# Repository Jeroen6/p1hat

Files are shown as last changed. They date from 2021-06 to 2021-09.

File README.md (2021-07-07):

# p1hat
Rasbperry Pi P1 Monitor (ztatz.nl) IO HAT

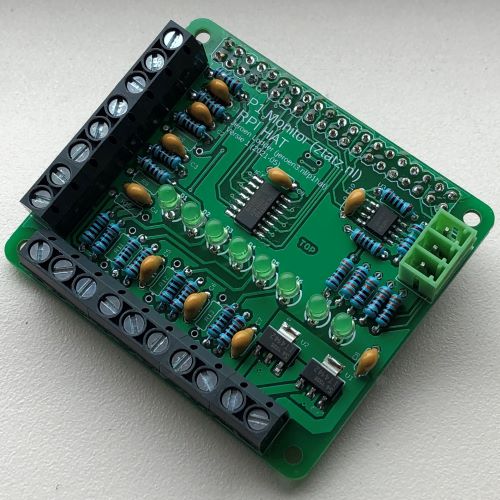
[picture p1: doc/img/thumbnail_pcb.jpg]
pcb


## Behuizing
Er is ook een behuizing!

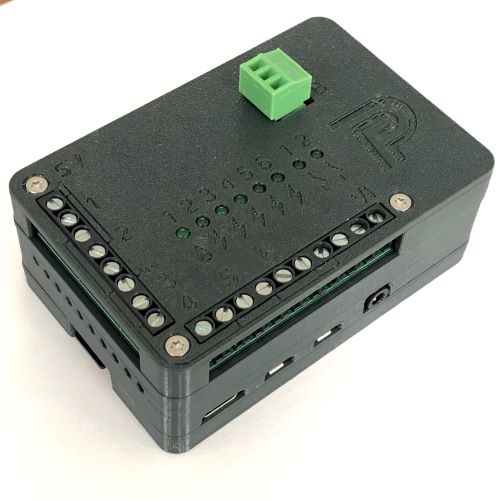
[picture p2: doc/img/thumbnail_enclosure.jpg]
render


## Aansluitingen

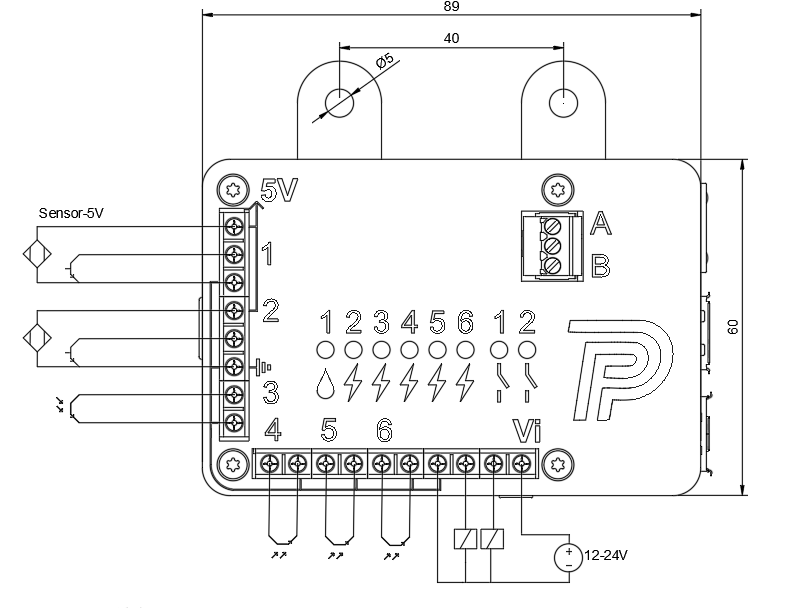
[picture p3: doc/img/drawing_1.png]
aansluitingen


## Inputs

Er zijn 6 gebufferde ingangen geschikt voor open-collector apparaten.
Zoals S0 pulsen van energiemeters of NPN type inductieve sensoren voor watermeters.

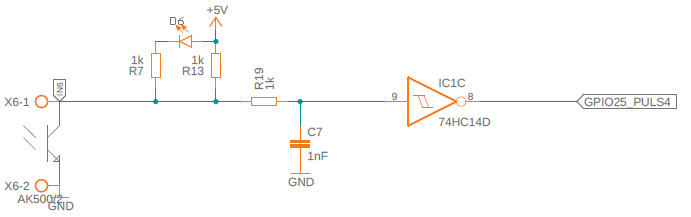
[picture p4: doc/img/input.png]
inputs


Het buffer is een 74LVC07A met schmitt trigger ingangen en open drain uitgangen. 
Hiervoor is het dus nodig om de pull-ups in de BCM te activeren. 
Een ander buffer kan ook, velen passen op deze SOIC footprint.

Het filternetwerk 1k/1nF dempt eventuele ingekoppelde storingen en de sterke pull-up van 1 kOhm voorkomt spontane detecties. *(van nabij schakelende relais, motoren of andere storingen)*  

> Als er schakelaars worden aangesloten dient dit netwerk wellicht te worden vertraagd, probeer 100k en 10nf. Of [debounce](https://en.wikipedia.org/wiki/Switch#Contact_bounce) in software.

## Outputs

Twee smart high side fets kunnen bijna elke 12/45V last schakelen.
 - Ze zijn geschikt voor high-side switching. 
 - Ze zijn geschikt voor inductieve lasten zonder vrijloop diode. (relais)
 - Ze zijn thermisch kortsluitbeveiligd.
 
Vrijwel niet kapot te krijgen.

## RS-485

Op de print zit een RS-485 tranceiver. Om bijvoorbeeld te praten met RS-485 energiemeters.
De middelste pin van de RS-485 header is GND, dit is meestal niet nodig.

> Hoe dit op de raspberry werkt moet ik nog uitzoeken.  

## GPIO Header

| Board | GPIO | Mode |
|---|---|---|
| IN1 | 17 | Pull-up |
| IN2 | 27 | Pull-up |
| IN3 | 22 | Pull-up |
| IN4 | 23 | Pull-up |
| IN5 | 24 | Pull-up |
| IN6 | 25 | Pull-up |
| OUT1 | 26 | Push-Pull  |
| OUT2 | 16 | Push-Pull  |
| RS485 TX | 14 | Alt0 |
| RS485 RX | 15 | Alt0 |
| RS485 TXENABLE | 18 | Push-Pull  |

## BOM

Lijst met onderdelen:

- PCB, zie .txt file in de map PCB voor onderdelen.
    - De onderdelen zijn te krijgen via Conrad, Reichelt of zelfs AliExpress of sinuss.nl (dat is farnell/avnet voor particulieren).
- Raspberry Pi 4 met SD kaart en P1 Monitor
- Behuizing 3D-geprint van PETG.
- Schroeven
    - 4x M2.5x16 Verzonken Torx (TX8) WS 9475TX
    - 4x M2.5x12 Verzonken Torx (TX8) WS 9475TX
        - Zie [rvspaleis.nl](https://www.rvspaleis.nl/bouten/torx/ws-9475/ws-9475-[-]-a2-[-]-m2,5)

> De 1 kOhm pull-ups parallel aan de LED heb ik op mijn print niet geplaatst. Mogelijk zijn deze bij andere typen, of geen, LED's wel nodig.

## Software

De gebruikte software is (gratis) Autodesk Fusion 360 voor niet-commercieel gebruik. 
De `*.f3z` bestanden zijn archieven hiervan.

## Suggesties of problemen?
Zet deze in de [Issues](https://github.com/Jeroen6/p1hat/issues) en vragen in [Discussions](https://github.com/Jeroen6/p1hat/discussions).

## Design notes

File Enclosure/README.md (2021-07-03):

## Wat is dit?

Ik heb twee modellen gemaakt.

1. Origineel gebaseerd op de RPI 4.
2. Kopie met wijzigingen voor RPI 3 op het middelste deel.  
En wijzigingen op de bovenkant zonder enige markings of gaatjes.

In de rpi3 versie step file zit de closed top.

## 3D Printen

Instructies voor printen van de `.stl`:

1. Print een bodem.
2. Print een middendeel voor jouw RPI type.
3. Print een top (zonder de hat kun je de _closed_ variant nemen)

Dit kan tegelijk.

> Let op bij het middendeel, print deze met de RPI zijde onder, die is vlak. Zet ook de supports aan voor de bridges rond de HDMI/USB plugs. In prusaslicer is "support on build plate only" voldoende.

## Fusion360

De twee `*.f3z` bestanden zijn de Fusion360 archieven, om verder te bewerken.

## Assemblage

Het is een sandwich en er is weinig keuzevrijheid.
De lange m2.5x16 schroef gaat boven aan de hat zijde.    
De korte m2.5x12 schroef gaat onder aan de pi zijde.  

De gaten zijn iets te klein, het fijne draad tapt erin. Dit is geen stevige montage.
Je draait dit snel dol, dus als de schroef gelijk is aan het oppervlak zit je goed.  
Het hoeft niet super vast.

Eventueel kun je het model bewerken of uitboren en er threaded-inserts in persen of smelten.

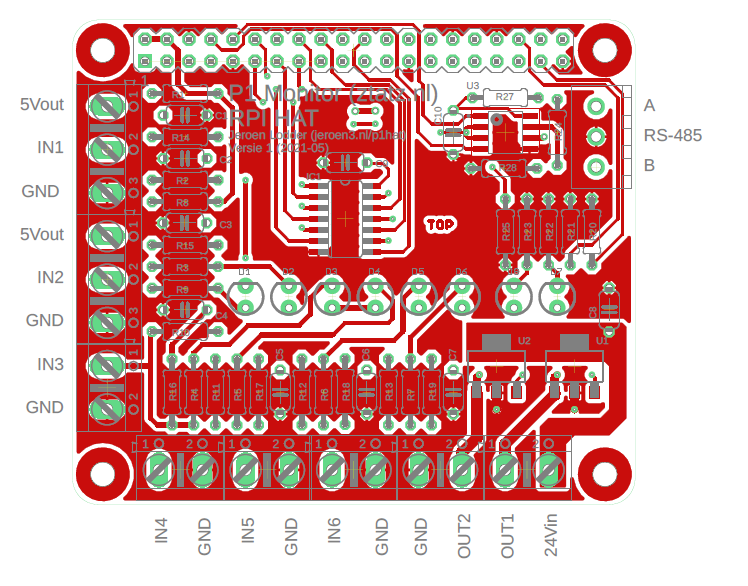
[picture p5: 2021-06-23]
doc/img/pcb-text.png

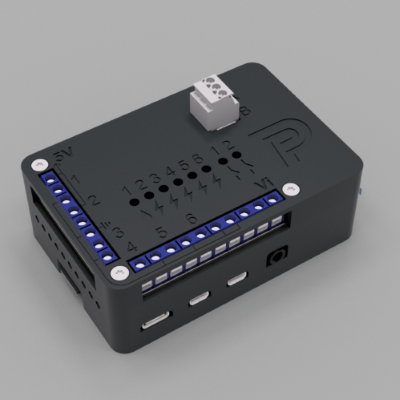
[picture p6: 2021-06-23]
doc/img/renderv20.png

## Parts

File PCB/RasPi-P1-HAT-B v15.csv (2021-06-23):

Part | Value | Device | Package | Description | DIELECTRIC | MF | MPN | OC_FARNELL | OC_NEWARK | POPULARITY | PROD_ID | SPICEPREFIX | TOLERANCE
C1 | 100nF | C-EU050-024X044 | C050-024X044 | CAPACITOR, European symbol | X7R |  |  |  |  | 33 |  | C
C2 | 1nF | C-EU050-024X044 | C050-024X044 | CAPACITOR, European symbol | X7R |  |  |  |  | 33 |  | C
C3 | 1nF | C-EU050-024X044 | C050-024X044 | CAPACITOR, European symbol | X7R |  |  |  |  | 33 |  | C
C4 | 1nF | C-EU050-024X044 | C050-024X044 | CAPACITOR, European symbol | X7R |  |  |  |  | 33 |  | C
C5 | 1nF | C-EU050-024X044 | C050-024X044 | CAPACITOR, European symbol | X7R |  |  |  |  | 33 |  | C
C6 | 1nF | C-EU050-024X044 | C050-024X044 | CAPACITOR, European symbol | X7R |  |  |  |  | 33 |  | C
C7 | 1nF | C-EU050-024X044 | C050-024X044 | CAPACITOR, European symbol | X7R |  |  |  |  | 33 |  | C
C8 | 100nF | C-EU050-024X044 | C050-024X044 | CAPACITOR, European symbol | X7R |  |  |  |  | 33 |  | C
C9 | 1nF | C-EU050-024X044 | C050-024X044 | CAPACITOR, European symbol | X7R |  |  |  |  | 33 |  | C
D1 |  | LED3MM | LED_3MM | LED (Generic) |  |  |  |  |  |  | DIO-08794
D2 |  | LED3MM | LED_3MM | LED (Generic) |  |  |  |  |  |  | DIO-08794
D3 |  | LED3MM | LED_3MM | LED (Generic) |  |  |  |  |  |  | DIO-08794
D4 |  | LED3MM | LED_3MM | LED (Generic) |  |  |  |  |  |  | DIO-08794
D5 |  | LED3MM | LED_3MM | LED (Generic) |  |  |  |  |  |  | DIO-08794
D6 |  | LED3MM | LED_3MM | LED (Generic) |  |  |  |  |  |  | DIO-08794
D7 |  | LED3MM | LED_3MM | LED (Generic) |  |  |  |  |  |  | DIO-08794
D8 |  | LED3MM | LED_3MM | LED (Generic) |  |  |  |  |  |  | DIO-08794
IC1 | 74HC14D | 74HC14D | SO14 | Hex schmitt trigger INVERTER |  |  |  |  |  | 0
K1 | SSW-120-23-G-D | PIN20X2 | PIN_20X2
R1 | 10 | R-EU_0204/7 | 0204/7 | RESISTOR, European symbol |  |  |  |  |  | 79 |  | R | 5%
R2 | 1k | R-EU_0204/7 | 0204/7 | RESISTOR, European symbol |  |  |  |  |  | 79 |  | R | 5%
R3 | 1k | R-EU_0204/7 | 0204/7 | RESISTOR, European symbol |  |  |  |  |  | 79 |  | R | 5%
R4 | 1k | R-EU_0204/7 | 0204/7 | RESISTOR, European symbol |  |  |  |  |  | 79 |  | R | 5%
R5 | 1k | R-EU_0204/7 | 0204/7 | RESISTOR, European symbol |  |  |  |  |  | 79 |  | R | 5%
R6 | 1k | R-EU_0204/7 | 0204/7 | RESISTOR, European symbol |  |  |  |  |  | 79 |  | R | 5%
R7 | 1k | R-EU_0204/7 | 0204/7 | RESISTOR, European symbol |  |  |  |  |  | 79 |  | R | 5%
R8 | 1k | R-EU_0204/7 | 0204/7 | RESISTOR, European symbol |  |  |  |  |  | 79 |  | R | 5%
R9 | 1k | R-EU_0204/7 | 0204/7 | RESISTOR, European symbol |  |  |  |  |  | 79 |  | R | 5%
R10 | 1k | R-EU_0204/7 | 0204/7 | RESISTOR, European symbol |  |  |  |  |  | 79 |  | R | 5%
R11 | 1k | R-EU_0204/7 | 0204/7 | RESISTOR, European symbol |  |  |  |  |  | 79 |  | R | 5%
R12 | 1k | R-EU_0204/7 | 0204/7 | RESISTOR, European symbol |  |  |  |  |  | 79 |  | R | 5%
R13 | 1k | R-EU_0204/7 | 0204/7 | RESISTOR, European symbol |  |  |  |  |  | 79 |  | R | 5%
R14 | 1k | R-EU_0204/7 | 0204/7 | RESISTOR, European symbol |  |  |  |  |  | 79 |  | R | 5%
R15 | 1k | R-EU_0204/7 | 0204/7 | RESISTOR, European symbol |  |  |  |  |  | 79 |  | R | 5%
R16 | 1k | R-EU_0204/7 | 0204/7 | RESISTOR, European symbol |  |  |  |  |  | 79 |  | R | 5%
R17 | 1k | R-EU_0204/7 | 0204/7 | RESISTOR, European symbol |  |  |  |  |  | 79 |  | R | 5%
R18 | 1k | R-EU_0204/7 | 0204/7 | RESISTOR, European symbol |  |  |  |  |  | 79 |  | R | 5%
R19 | 1k | R-EU_0204/7 | 0204/7 | RESISTOR, European symbol |  |  |  |  |  | 79 |  | R | 5%
R20 | 3k9 | R-EU_0204/7 | 0204/7 | RESISTOR, European symbol |  |  |  |  |  | 79 |  | R | 5%
R21 | 3k9 | R-EU_0204/7 | 0204/7 | RESISTOR, European symbol |  |  |  |  |  | 79 |  | R | 5%
R22 | 3k9 | R-EU_0204/7 | 0204/7 | RESISTOR, European symbol |  |  |  |  |  | 79 |  | R | 5%
R23 | 3k9 | R-EU_0204/7 | 0204/7 | RESISTOR, European symbol |  |  |  |  |  | 79 |  | R | 5%
U1 | BTS4141N | BTS4141N";PG-SOT-223"
U2 | BTS4141N | BTS4141N";PG-SOT-223"
X1 | AK500/3 | AK500/3 | AK500/3 | CONNECTOR |  |  |  | unknown | unknown | 3
X2 | AK500/3 | AK500/3 | AK500/3 | CONNECTOR |  |  |  | unknown | unknown | 3
X3 | AK500/2 | AK500/2 | AK500/2 | CONNECTOR |  |  |  | unknown | unknown | 14
X4 | AK500/2 | AK500/2 | AK500/2 | CONNECTOR |  |  |  | unknown | unknown | 14
X5 | AK500/2 | AK500/2 | AK500/2 | CONNECTOR |  |  |  | unknown | unknown | 14
X6 | AK500/2 | AK500/2 | AK500/2 | CONNECTOR |  |  |  | unknown | unknown | 14
X7 | AK500/2 | AK500/2 | AK500/2 | CONNECTOR |  |  |  | unknown | unknown | 14
X8 | AK500/2 | AK500/2 | AK500/2 | CONNECTOR |  |  |  | unknown | unknown | 14

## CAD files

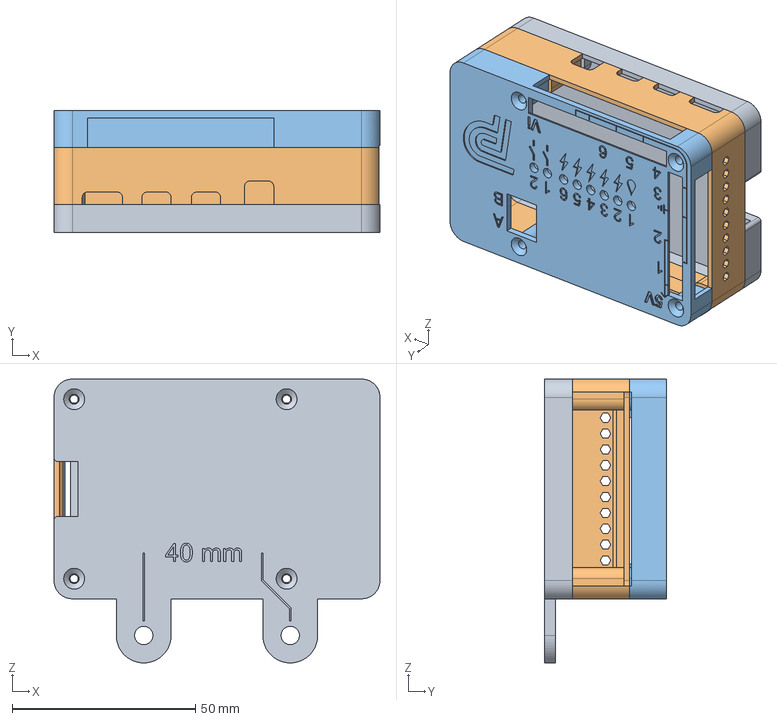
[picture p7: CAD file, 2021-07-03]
Enclosure/Assembly-RasPi-P1-HAT-B v22.step
89.0 x 33.2 x 77.5 mm

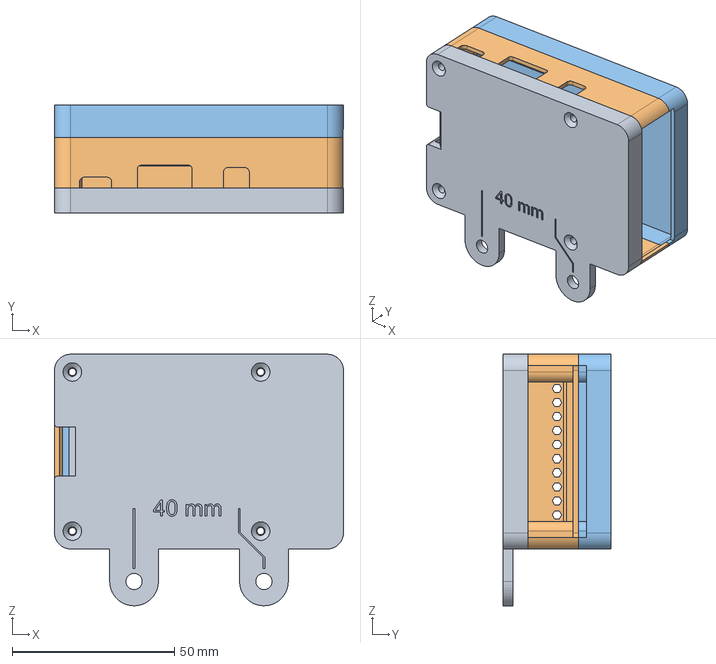
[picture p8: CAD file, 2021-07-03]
Enclosure/Assembly-RasPi-P1-HAT-B-rpi3 v4.step
89.0 x 33.2 x 77.5 mm

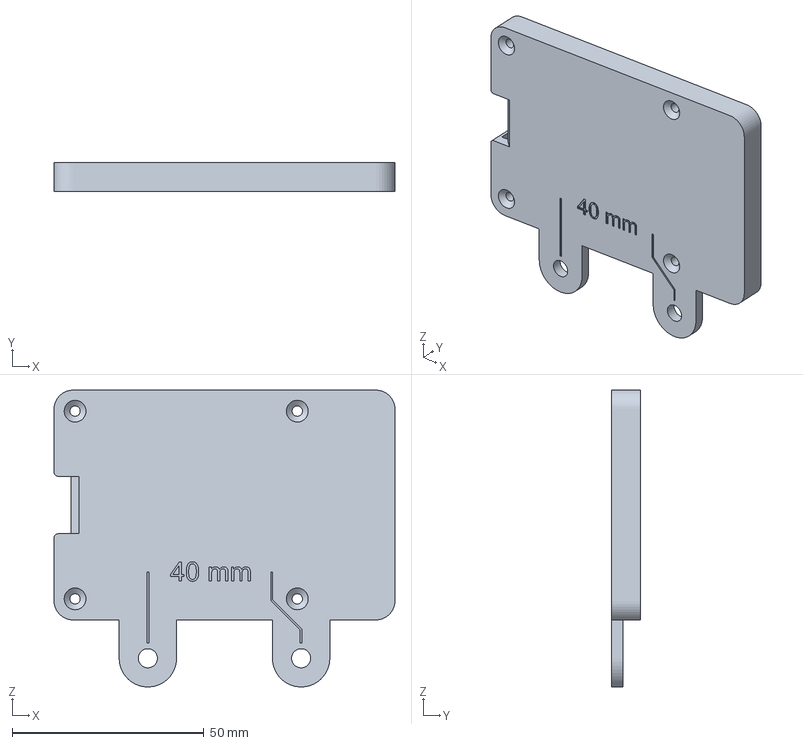
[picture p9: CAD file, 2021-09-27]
Enclosure/p1hat rpi box - Bottom.3mf
89.0 x 7.60 x 77.5 mm

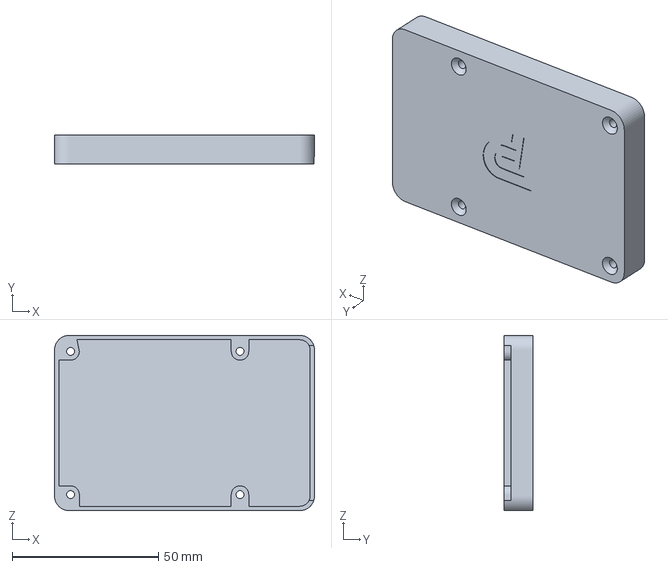
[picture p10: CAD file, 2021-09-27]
Enclosure/p1hat rpi box - Top p1mon solid.3mf
89.0 x 10.0 x 60.0 mm

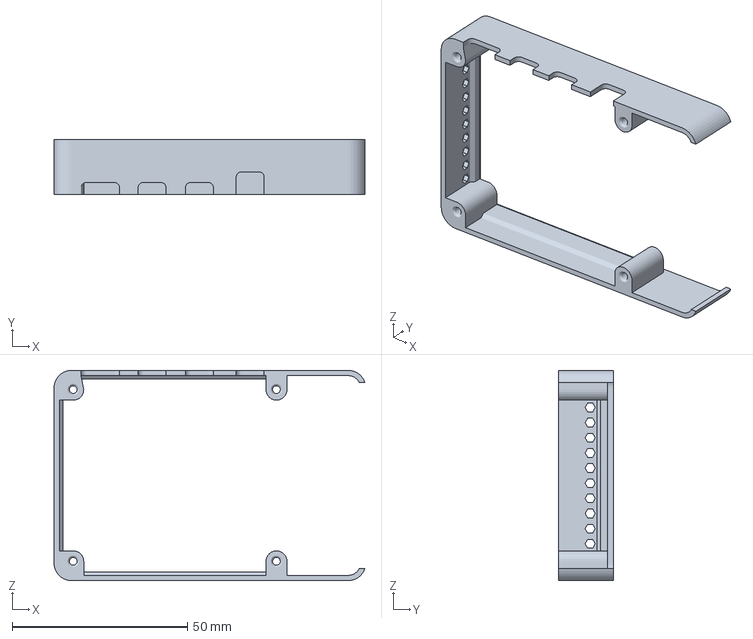
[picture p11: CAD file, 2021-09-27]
Enclosure/p1hat rpi box - Center rpi4.3mf
88.8 x 15.6 x 60.0 mm

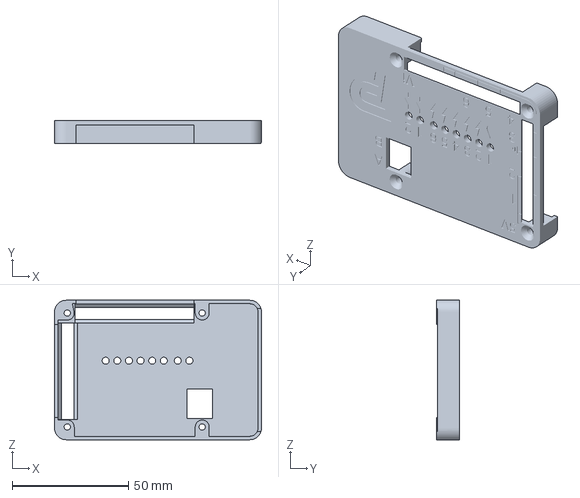
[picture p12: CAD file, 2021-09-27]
Enclosure/p1hat rpi box - Top p1mon hat.3mf
89.0 x 10.0 x 60.0 mm

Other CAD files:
Enclosure/p1hat rpi box - Center rpi3.3mf
Enclosure/p1hat rpi box - Top solid.3mf
Enclosure/Assembly-RasPi-P1-HAT-B v26.f3z
Enclosure/Assembly-RasPi-P1-HAT-B-rpi3 v8.f3z

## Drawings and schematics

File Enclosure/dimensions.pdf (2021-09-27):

# 44.52 Sensor-5V 12-24V

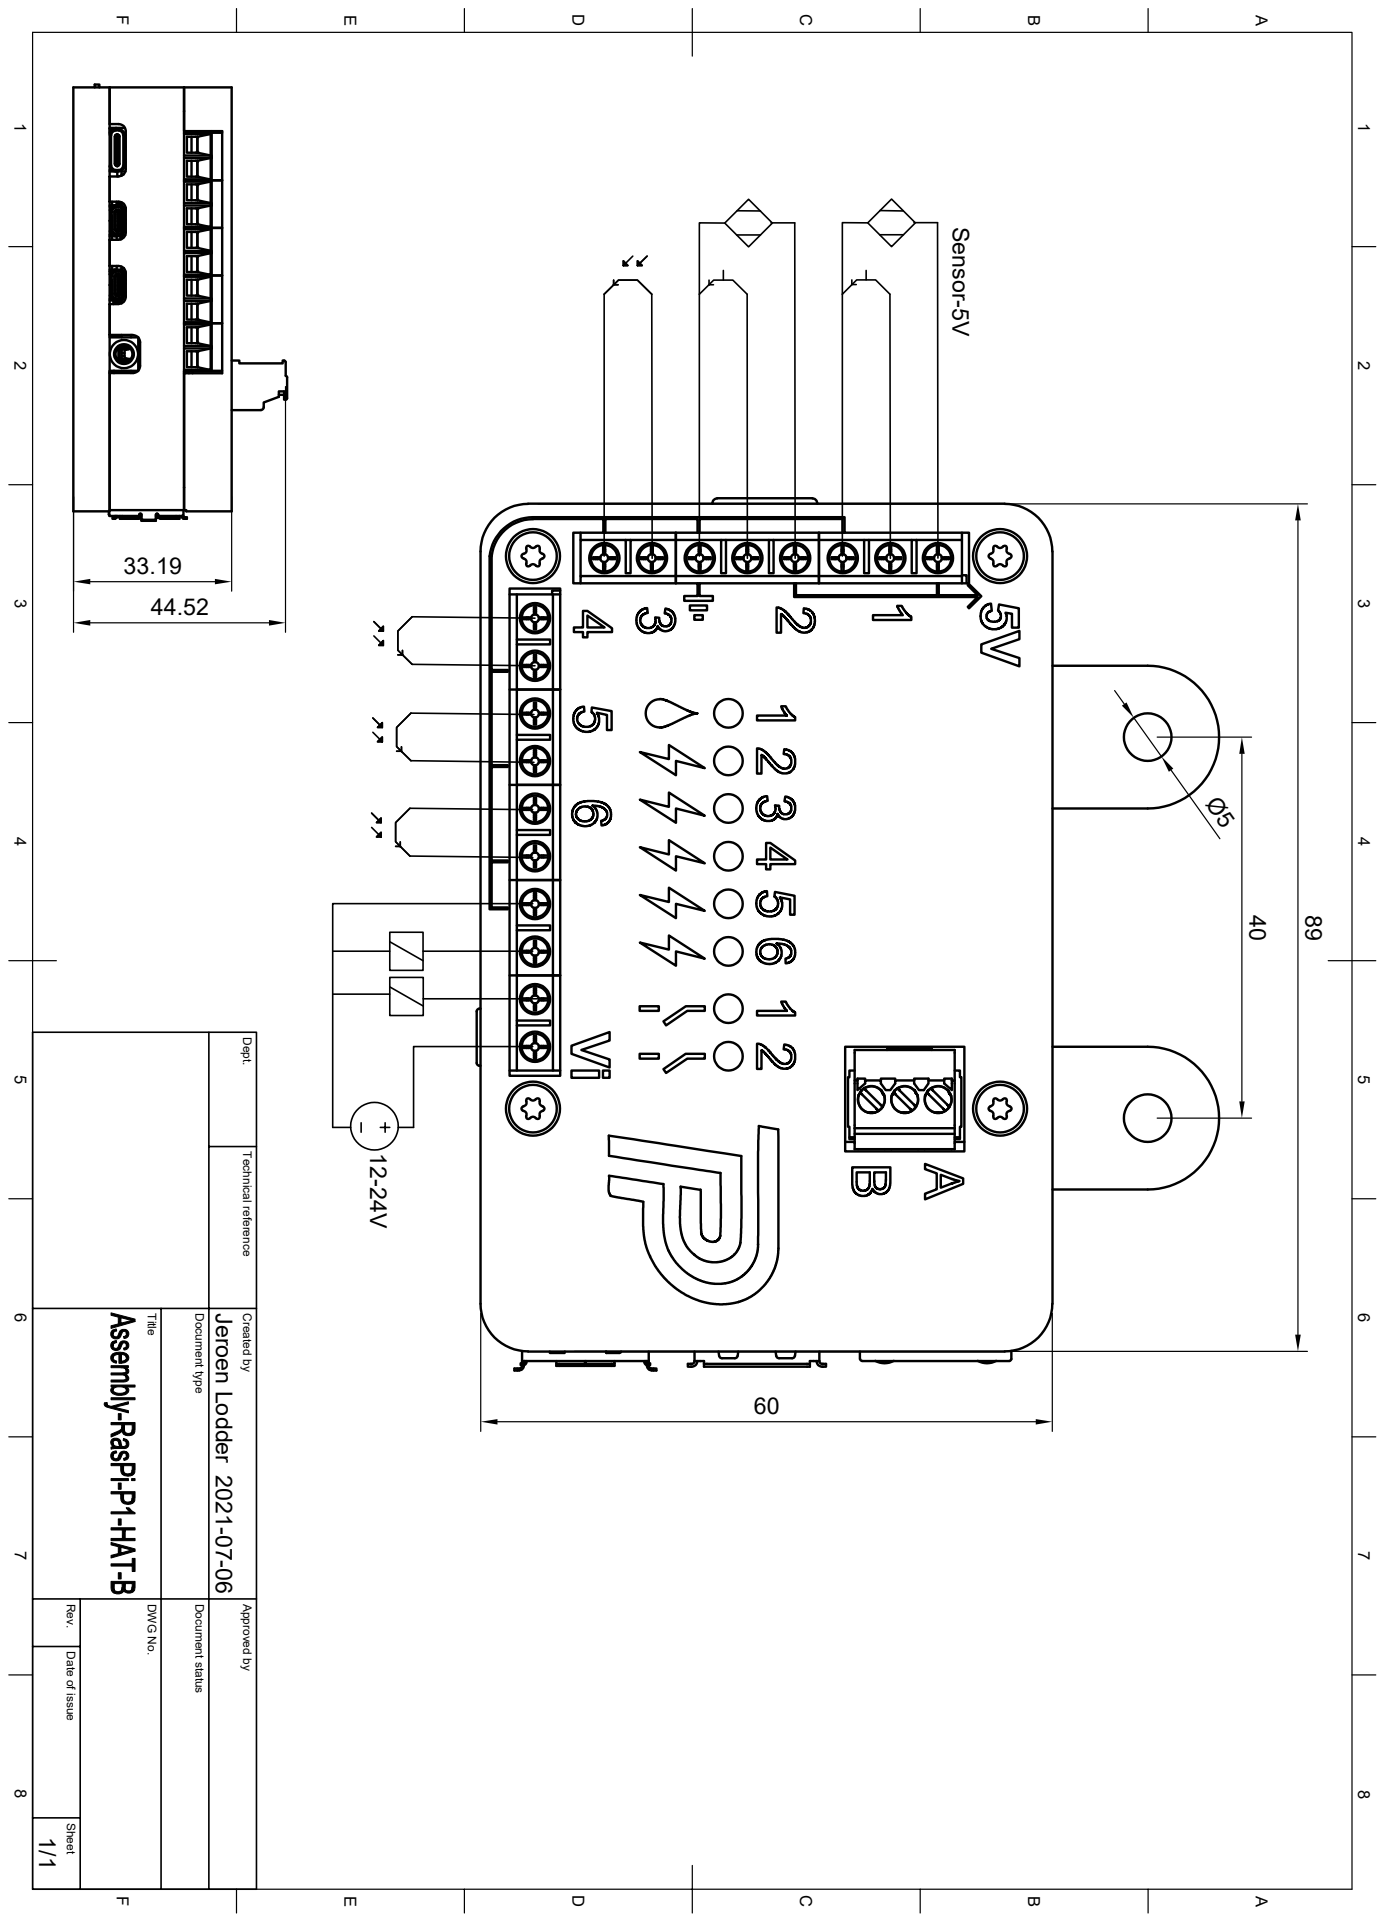
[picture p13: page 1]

1 A 2 3 4 5 6 7 8 1 2 3 4 5 6 7 8 FEDCB FEDCBA Dept. Technical reference Created by Approved by Title DWG No. Document type Document status Rev. Date of issue Sheet 2021-07-06 1/1 Jeroen Lodder 40 Ø5 89

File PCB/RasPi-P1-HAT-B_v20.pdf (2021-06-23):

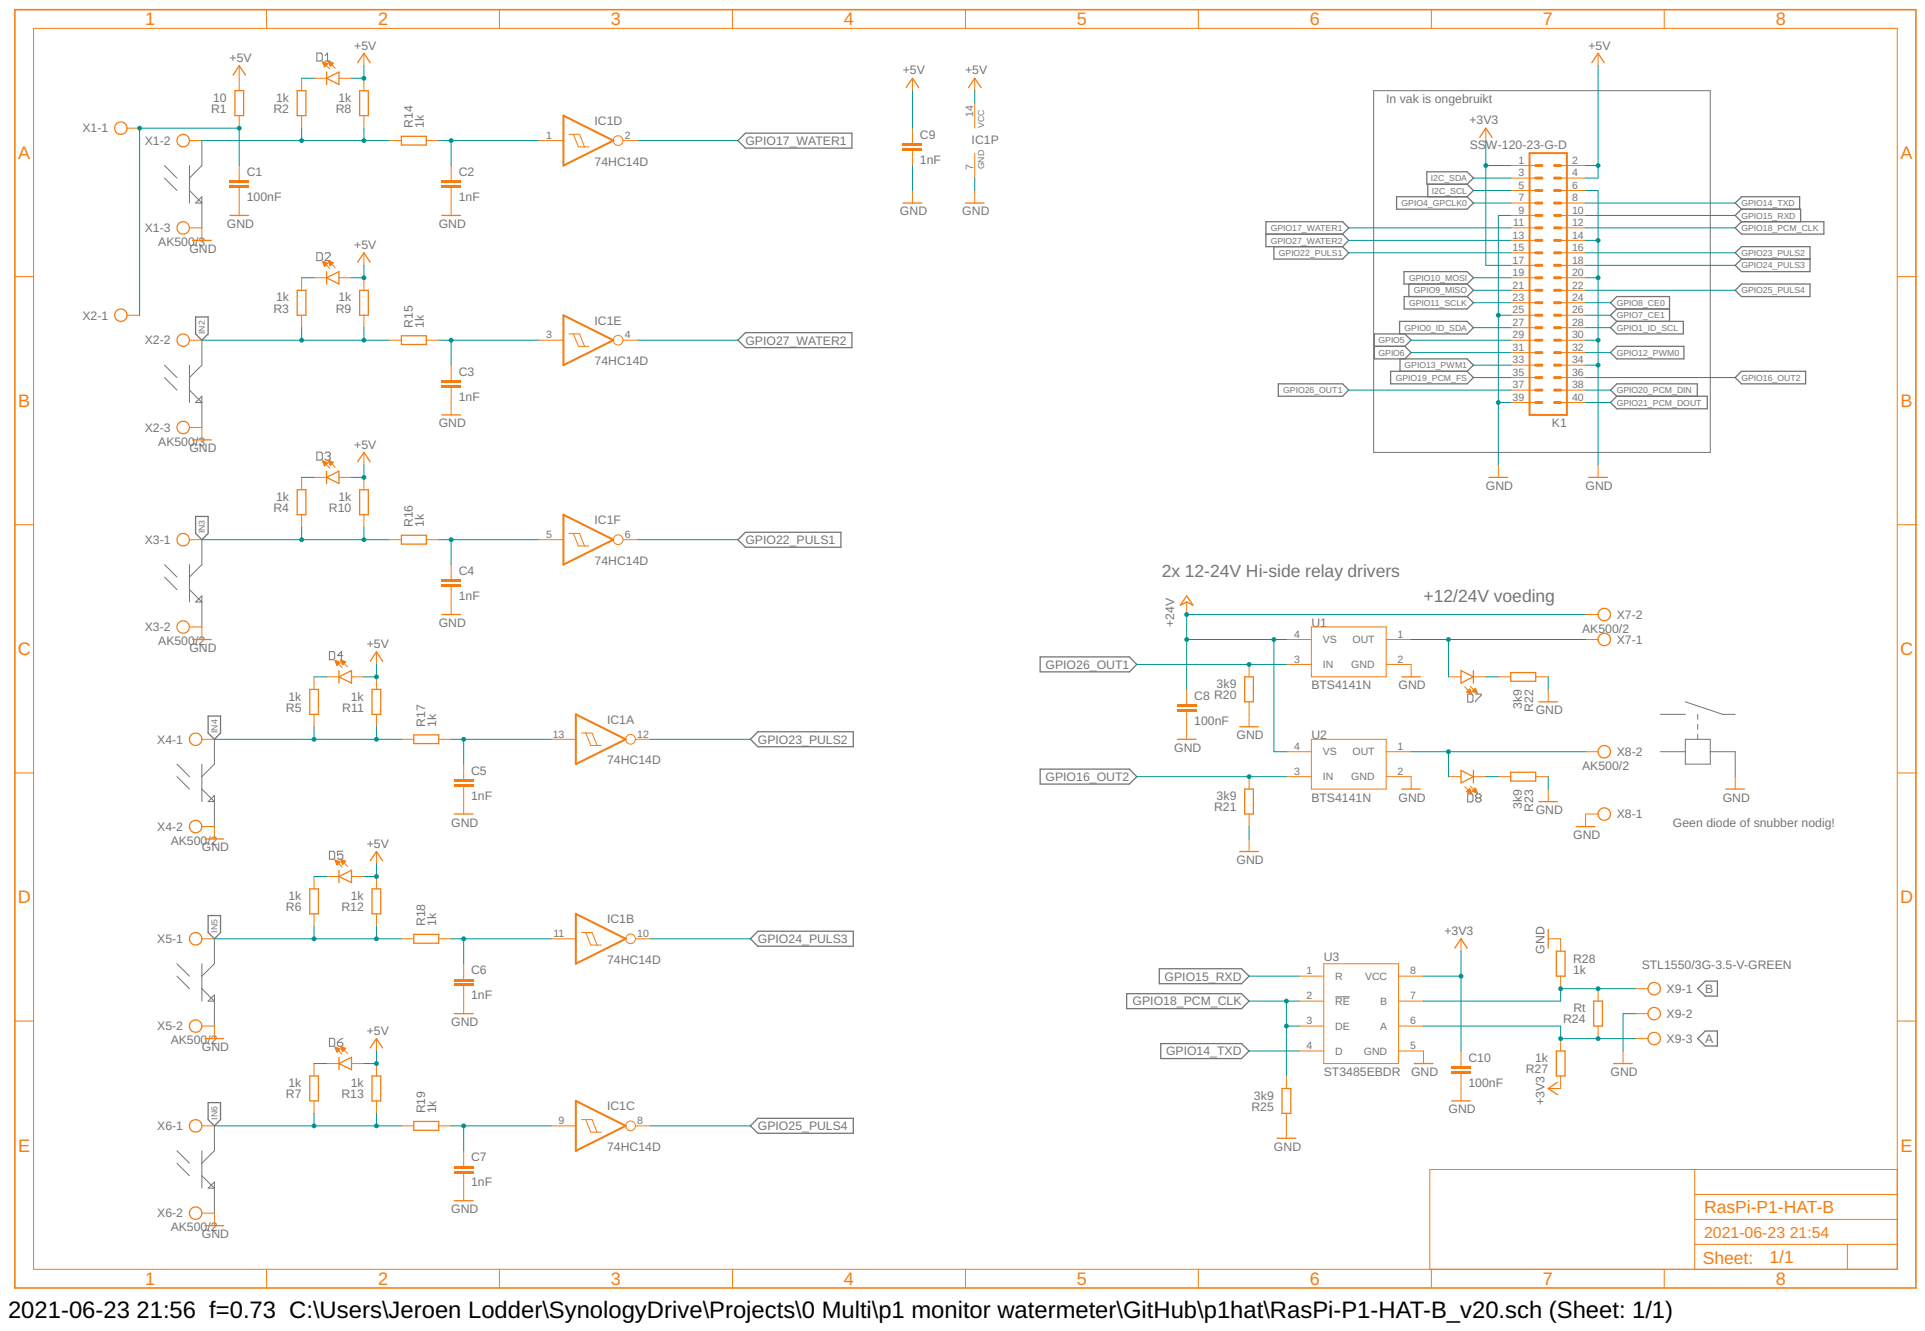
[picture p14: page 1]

In vak is ongebruikt +3V3 SSW-120-23-G-D GPIO4_GPCLK0 GPIO17_WATER1

11 13 15 17 | 12 | GPIO15_RXD

Geen diode of snubber nodig!

2021-06-23 21:56 f=0.73 C:\Users\Jeroen Lodder\SynologyDrive\Projects\0 Multi\p1 monitor watermeter\GitHub\p1hat\RasPi-P1-HAT-B_v20.sch (Sheet: 1/1)

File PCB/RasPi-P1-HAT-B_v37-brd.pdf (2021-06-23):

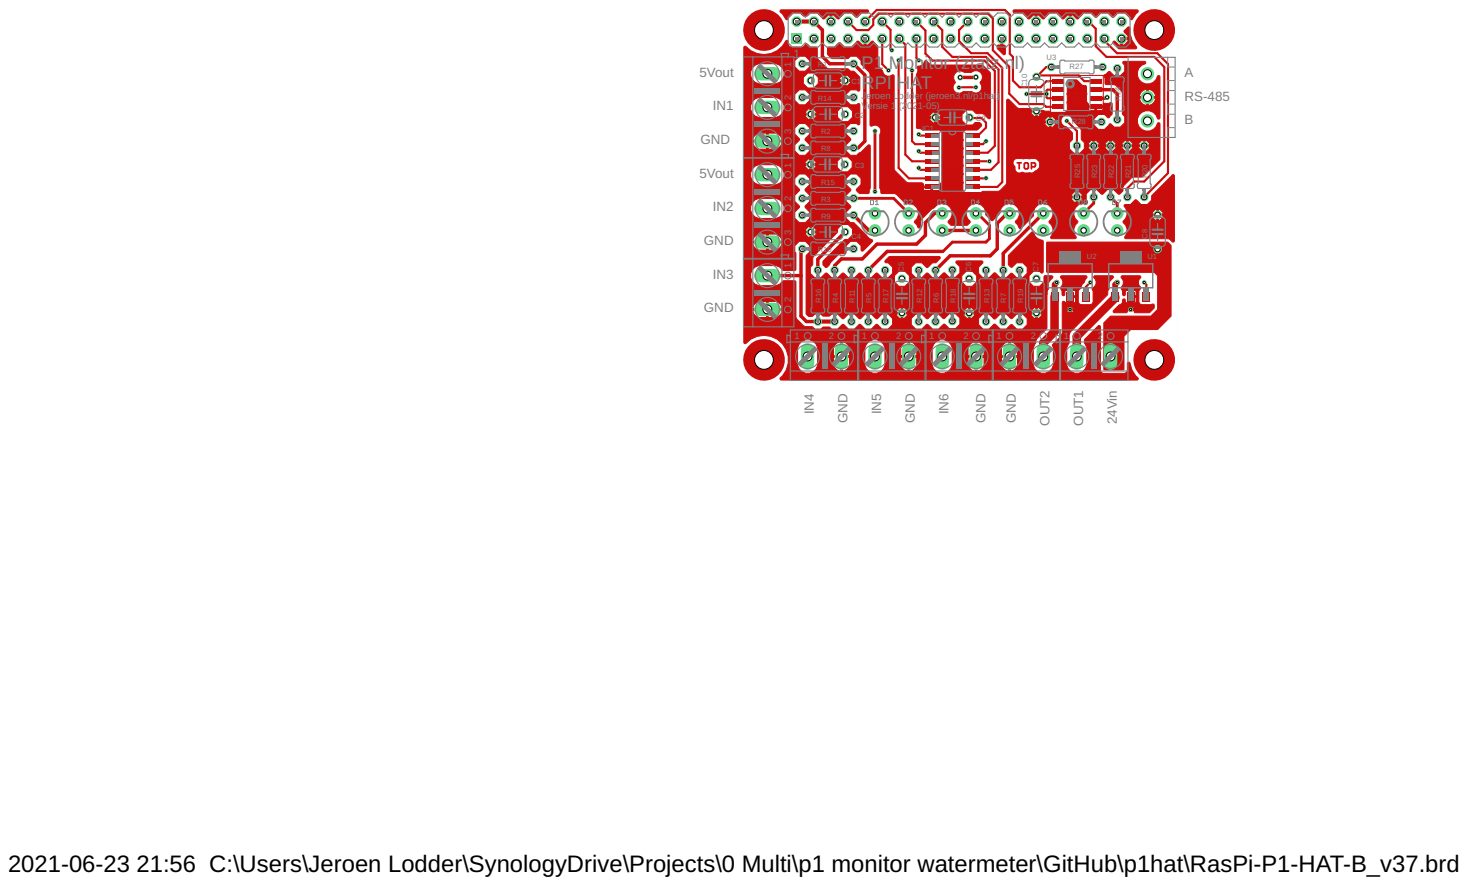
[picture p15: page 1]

IN6 GND GND GND GND

2021-06-23 21:56 C:\Users\Jeroen Lodder\SynologyDrive\Projects\0 Multi\p1 monitor watermeter\GitHub\p1hat\RasPi-P1-HAT-B_v37.brd

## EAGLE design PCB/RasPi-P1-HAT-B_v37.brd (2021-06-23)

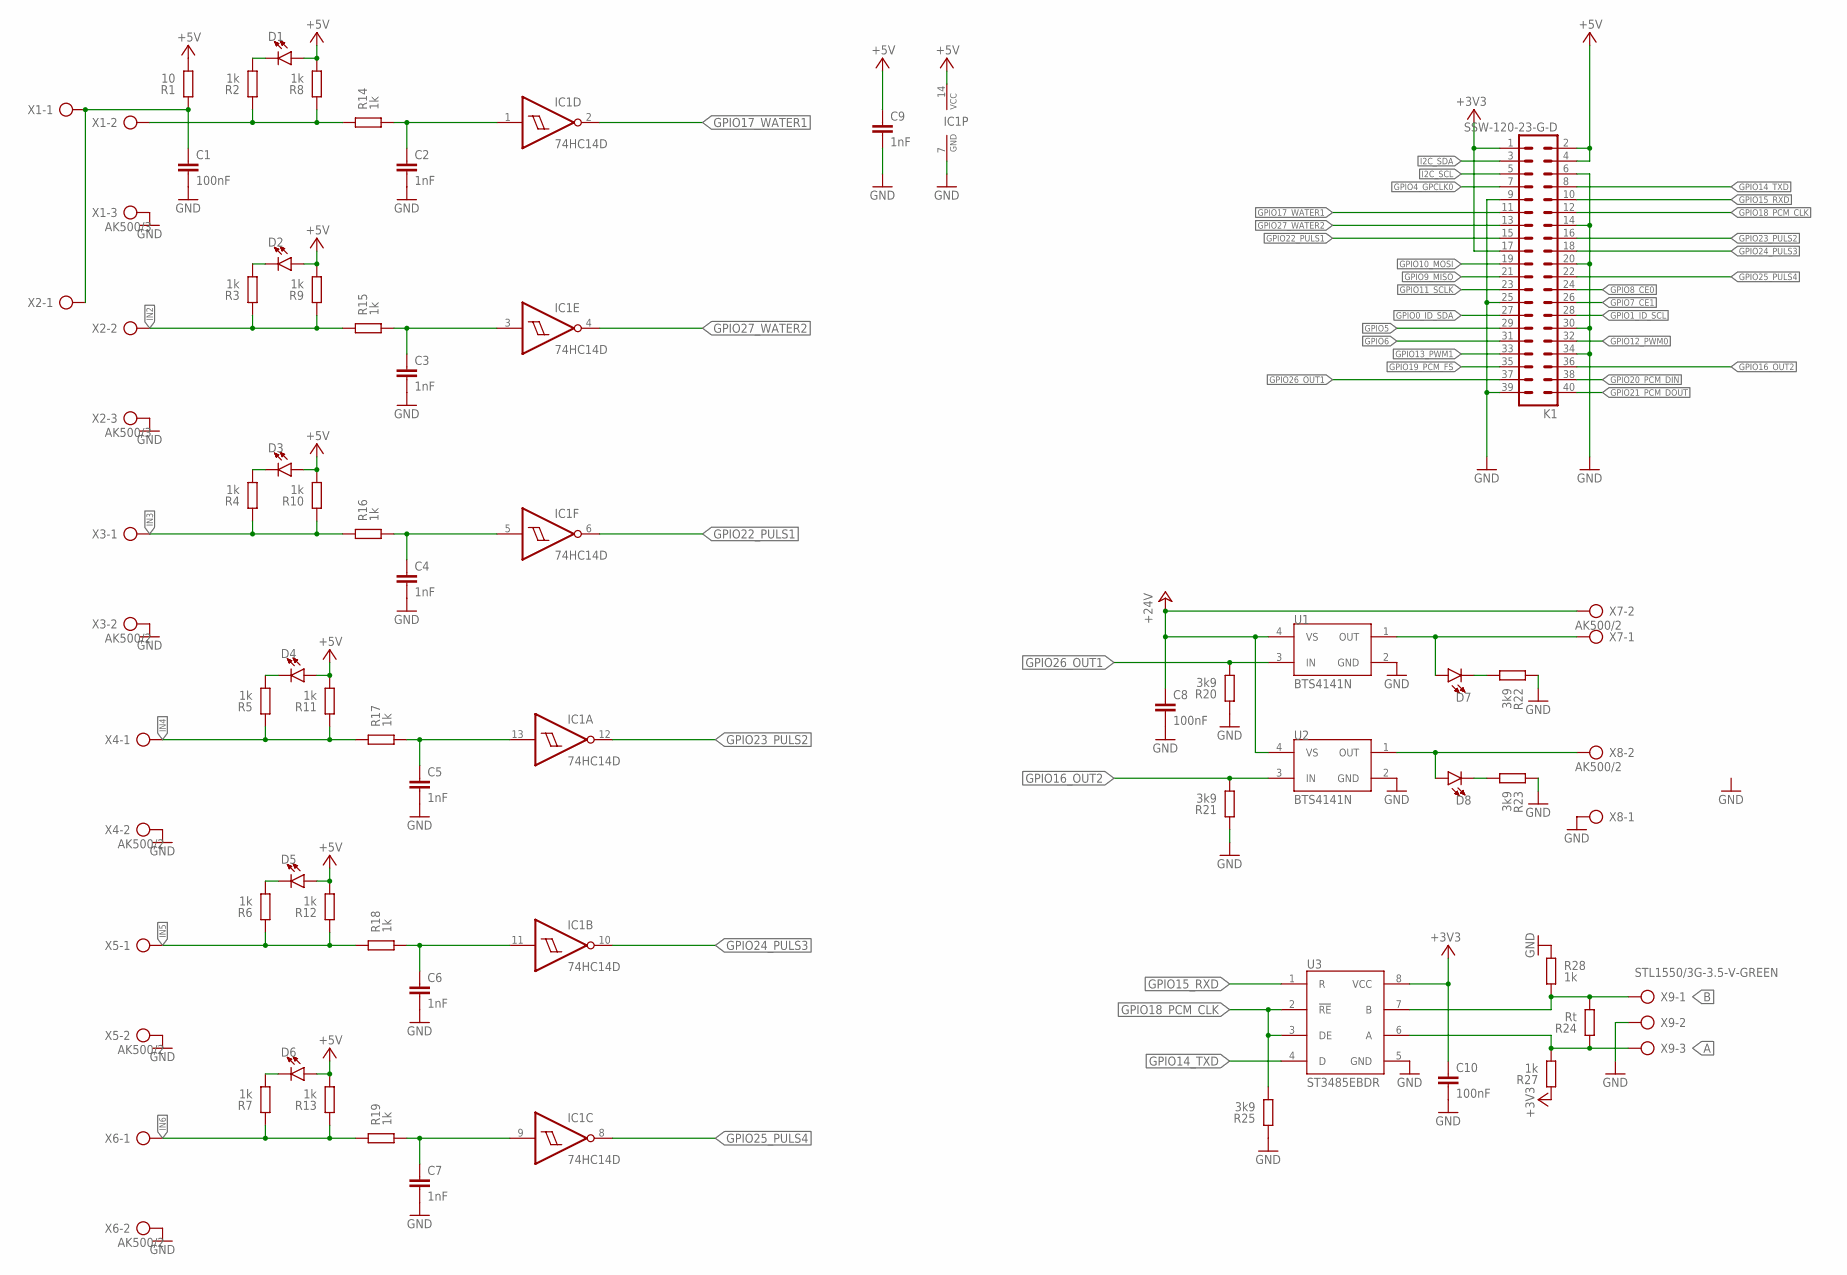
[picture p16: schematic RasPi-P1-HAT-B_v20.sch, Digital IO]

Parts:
C1, C8, C10: 100nF; C050-024X044
C2, C3, C4, C5, C6, C7, C9: 1nF; C050-024X044
D1, D2, D3, D4, D5, D6, D7, D8: LED3MM; LED_3MM
IC1: 74HC14D; SO14
K1: SSW-120-23-G-D; PIN_20X2
R1: 10; 0204/7; TOLERANCE 5%
R2, R3, R4, R5, R6, R7, R8, R9, R10, R11, R12, R13, R14, R15, R16, R17, R18, R19, R27, R28: 1k; 0204/7; TOLERANCE 5%
R20, R21, R22, R23, R25: 3k9; 0204/7; TOLERANCE 5%
R24: Rt; 0204/7; TOLERANCE 5%
U1, U2: BTS4141N; PG-SOT-223
U3: ST3485EBDR; SOIC-8
X1, X2: AK500/3
X3, X4, X5, X6, X7, X8: AK500/2
X9: STL1550/3G-3.5-V-GREEN; STL1550/3G-3.5-V-

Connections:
+3V3: C10.1, K1.1, K1.17, R27.2, U3.8 (VCC)
+5V: C9.1, D1.A, D2.A, D3.A, D4.A, D5.A, D6.A, IC1.14 (VCC), K1.2, K1.4, R1.1, R8.1, R9.1, R10.1, R11.1, R12.1, R13.1
+24V: C8.1, U1.4 (VS), U2.4 (VS), X7.2
A: R24.2, R27.1, U3.6 (A), X9.P$3
B: R24.1, R28.1, U3.7 (B), X9.P$1
GND: C1.2, C2.2, C3.2, C4.2, C5.2, C6.2, C7.2, C8.2, C9.2, C10.2, IC1.7 (GND), K1.6, K1.9, K1.14, K1.20, K1.25, K1.30, K1.34, K1.39, R20.2, R21.2, R22.2, R23.2, R25.2, R28.2, U1.2 (GND), U2.2 (GND), U3.5 (GND), X1.3, X2.3, X3.2, X4.2, X5.2, X6.2, X8.1, X9.P$2
GPIO0_ID_SDA: K1.27
GPIO1_ID_SCL: K1.28
GPIO4_GPCLK0: K1.7
GPIO5: K1.29
GPIO6: K1.31
GPIO7_CE1: K1.26
GPIO8_CE0: K1.24
GPIO9_MISO: K1.21
GPIO10_MOSI: K1.19
GPIO11_SCLK: K1.23
GPIO12_PWM0: K1.32
GPIO13_PWM1: K1.33
GPIO14_TXD: K1.8, U3.4 (D)
GPIO15_RXD: K1.10, U3.1 (R)
GPIO16_OUT2: K1.36, R21.1, U2.3 (IN)
GPIO17_WATER1: IC1.2 (O), K1.11
GPIO18_PCM_CLK: K1.12, R25.1, U3.2 (!RE), U3.3 (DE)
GPIO19_PCM_FS: K1.35
GPIO20_PCM_DIN: K1.38
GPIO21_PCM_DOUT: K1.40
GPIO22_PULS1: IC1.6 (O), K1.15
GPIO23_PULS2: IC1.12 (O), K1.16
GPIO24_PULS3: IC1.10 (O), K1.18
GPIO25_PULS4: IC1.8 (O), K1.22
GPIO26_OUT1: K1.37, R20.1, U1.3 (IN)
GPIO27_WATER2: IC1.4 (O), K1.13
I2C_SCL: K1.5
I2C_SDA: K1.3
IN1: R2.2, R8.2, R14.2, X1.2
IN1_1: C2.1, IC1.1 (I), R14.1
IN2: R3.2, R9.2, R15.2, X2.2
IN2_1: C3.1, IC1.3 (I), R15.1
IN3: R4.2, R10.2, R16.2, X3.1
IN3_1: C4.1, IC1.5 (I), R16.1
IN4: R5.2, R11.2, R17.2, X4.1
IN5: R6.2, R12.2, R18.2, X5.1
IN6: R7.2, R13.2, R19.2, X6.1
unnamed: D6.K (C), R7.1
unnamed: D5.K (C), R6.1
unnamed: D4.K (C), R5.1
unnamed: D7.K (C), R22.1
unnamed: D8.K (C), R23.1
unnamed: D3.K (C), R4.1
unnamed: D2.K (C), R3.1
unnamed: D1.K (C), R2.1
unnamed: C5.1, IC1.13 (I), R17.1
unnamed: C6.1, IC1.11 (I), R18.1
unnamed: C7.1, IC1.9 (I), R19.1
unnamed: C1.1, R1.2, X1.1, X2.1
OUT1: D7.A, U1.1 (OUT), X7.1
OUT2: D8.A, U2.1 (OUT), X8.2

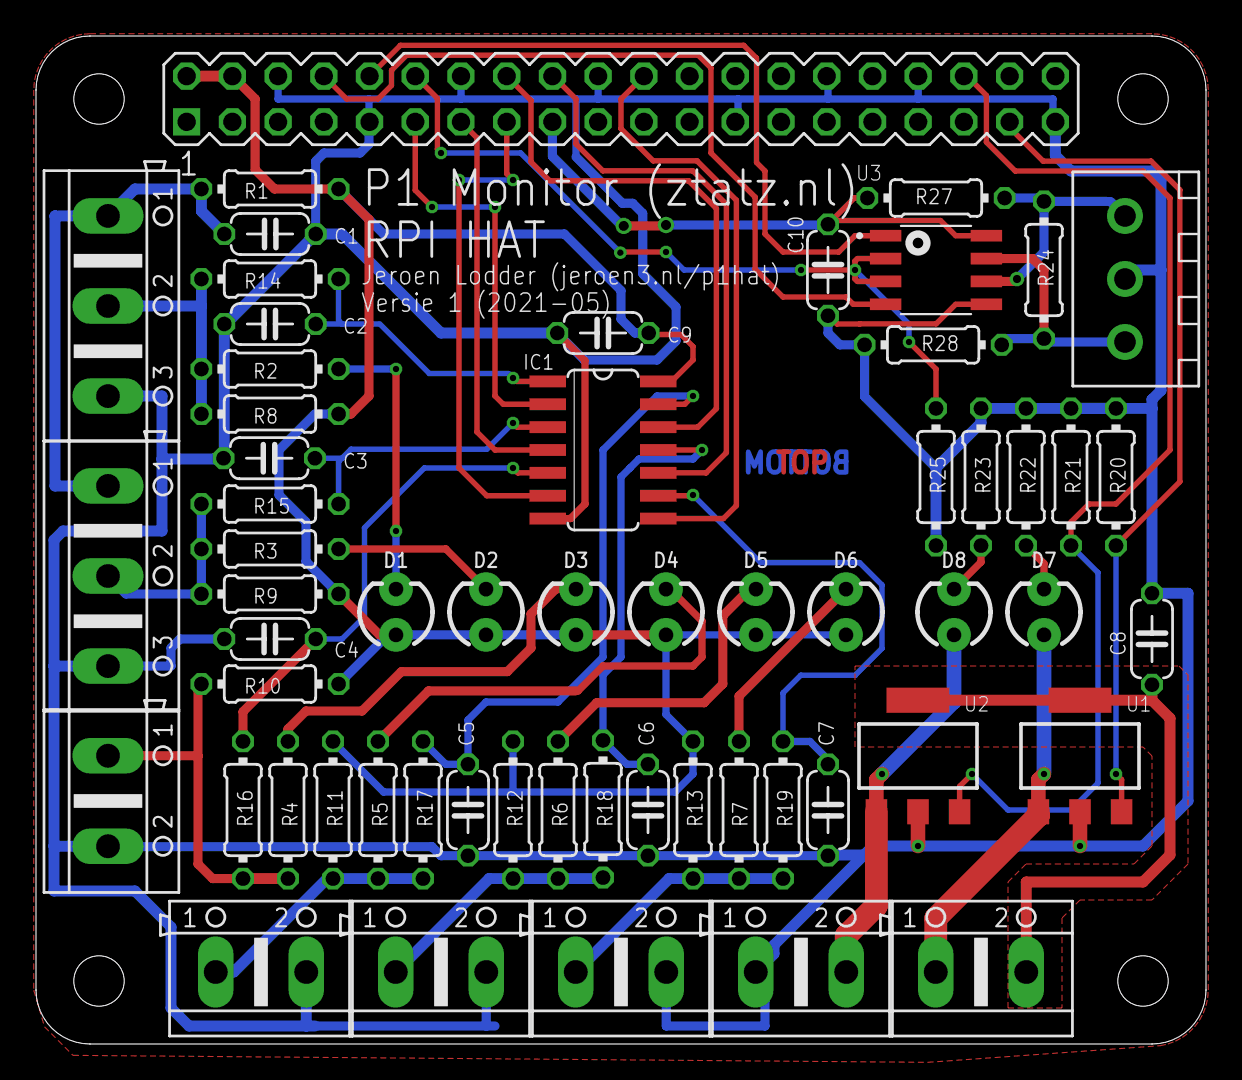
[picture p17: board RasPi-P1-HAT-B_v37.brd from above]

Board: 2 copper layers, 65.0 x 56.0 mm, 60 parts (1 on the bottom side), 40 nets.

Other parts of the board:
U$3: MUELLTONNE_10.00

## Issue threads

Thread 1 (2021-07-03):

BTS4141N output-clamp [Von(cl)] dan groter dan reverse voltage [Vr] van LED

Jeroen6, 2021-07-03:
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

Bij het uitschakelen van een relais gaat de inductieve fly-back terug in de smart switch. Deze heeft een rated 62-85 Volt clamp rating. Met een testrelais maakt deze een piek van -56 V.

LED's hebben geen hoge reverse voltage rating, er moet wellicht er een extra diode in serie met de LED om niet in reverse breakdown te komen.

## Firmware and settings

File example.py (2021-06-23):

import RPi.GPIO as gpio
import time

IN1 = 17
IN2 = 27
IN3 = 22
IN4 = 23
IN5 = 24
IN6 = 25
OUT1 = 26
OUT2 = 16
RXD = 15
TXD = 14
TXEN = 18

gpio.setmode(gpio.BCM)
gpio.setwarnings(False)
gpio.setup(OUT1, gpio.OUT)
gpio.setup(OUT2, gpio.OUT)
gpio.setup(IN1, gpio.IN, pull_up_down=gpio.PUD_UP)
gpio.setup(IN2, gpio.IN, pull_up_down=gpio.PUD_UP)
gpio.setup(IN3, gpio.IN, pull_up_down=gpio.PUD_UP)
gpio.setup(IN4, gpio.IN, pull_up_down=gpio.PUD_UP)
gpio.setup(IN5, gpio.IN, pull_up_down=gpio.PUD_UP)
gpio.setup(IN6, gpio.IN, pull_up_down=gpio.PUD_UP)
gpio.setup(TXEN, gpio.OUT)

toggle = False

ins = [IN1,IN2,IN3,IN4,IN5,IN6]
in_state = [0,0,0,0,0,0]

timeout = time.time() + 1  # 1 second from now
while True:
    test = 0
    if time.time() > timeout:
        timeout  = timeout + 1
        if(toggle):
            toggle = False
            gpio.output(OUT1, gpio.LOW)
            gpio.output(OUT2, gpio.HIGH)
            gpio.output(TXEN, gpio.HIGH)
        else:
            toggle = True
            gpio.output(OUT1, gpio.HIGH)
            gpio.output(OUT2, gpio.LOW)
            gpio.output(TXEN, gpio.HIGH)
    for i in range(6):
        pin = gpio.input(ins[i])
        if(in_state[i] != pin and pin == 0):
            print(str(time.time()) + "  "+  str(i))
        in_state[i] = pin
    
GPIO.cleanup()

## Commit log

2021-06-23 Upload data
    [Assembly-RasPi-P1-HAT-B v18_Assembly-RasPi-P1-HAT-B v18_p1hat pi box - Bodem_.stl, Assembly-RasPi-P1-HAT-B v18_Assembly-RasPi-P1-HAT-B v18_p1hat pi box - Midde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]
2021-07-03 Middendeel behuizing verhoogd vanwege onjuiste maat rpi header
    [Assembly-RasPi-P1-HAT-B v18_Assembly-RasPi-P1-HAT-B v18_p1hat pi box - Bodem_.stl, Assembly-RasPi-P1-HAT-B v18_Assembly-RasPi-P1-HAT-B v18_p1hat pi box - Midde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]
2021-09-27 Update filenames
    [Assembly-RasPi-P1-HAT-B v26.f3z, Assembly-RasPi-P1-HAT-B-rpi3 v8.f3z, p1hat pi box - Bodem.stl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]
2021-11-23 add gerber zip archive for pcb ordering
